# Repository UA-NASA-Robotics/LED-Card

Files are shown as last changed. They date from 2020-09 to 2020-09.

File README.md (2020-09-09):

# LED-Card
LED Card for the 2020-21 bot

## Design Specs

Interfaces with LED buffers for neopixels

Flash different statuses (listed below)

## CAN Bus information

### Status Lights
Red/Blue: Not connected

Green: Connected in Manual mode

Purple: Connected in Autonomous mode

### Planned features
Scrolling colors (flashy)

Digging mode colors

More Statuses

Overall more awesomeness

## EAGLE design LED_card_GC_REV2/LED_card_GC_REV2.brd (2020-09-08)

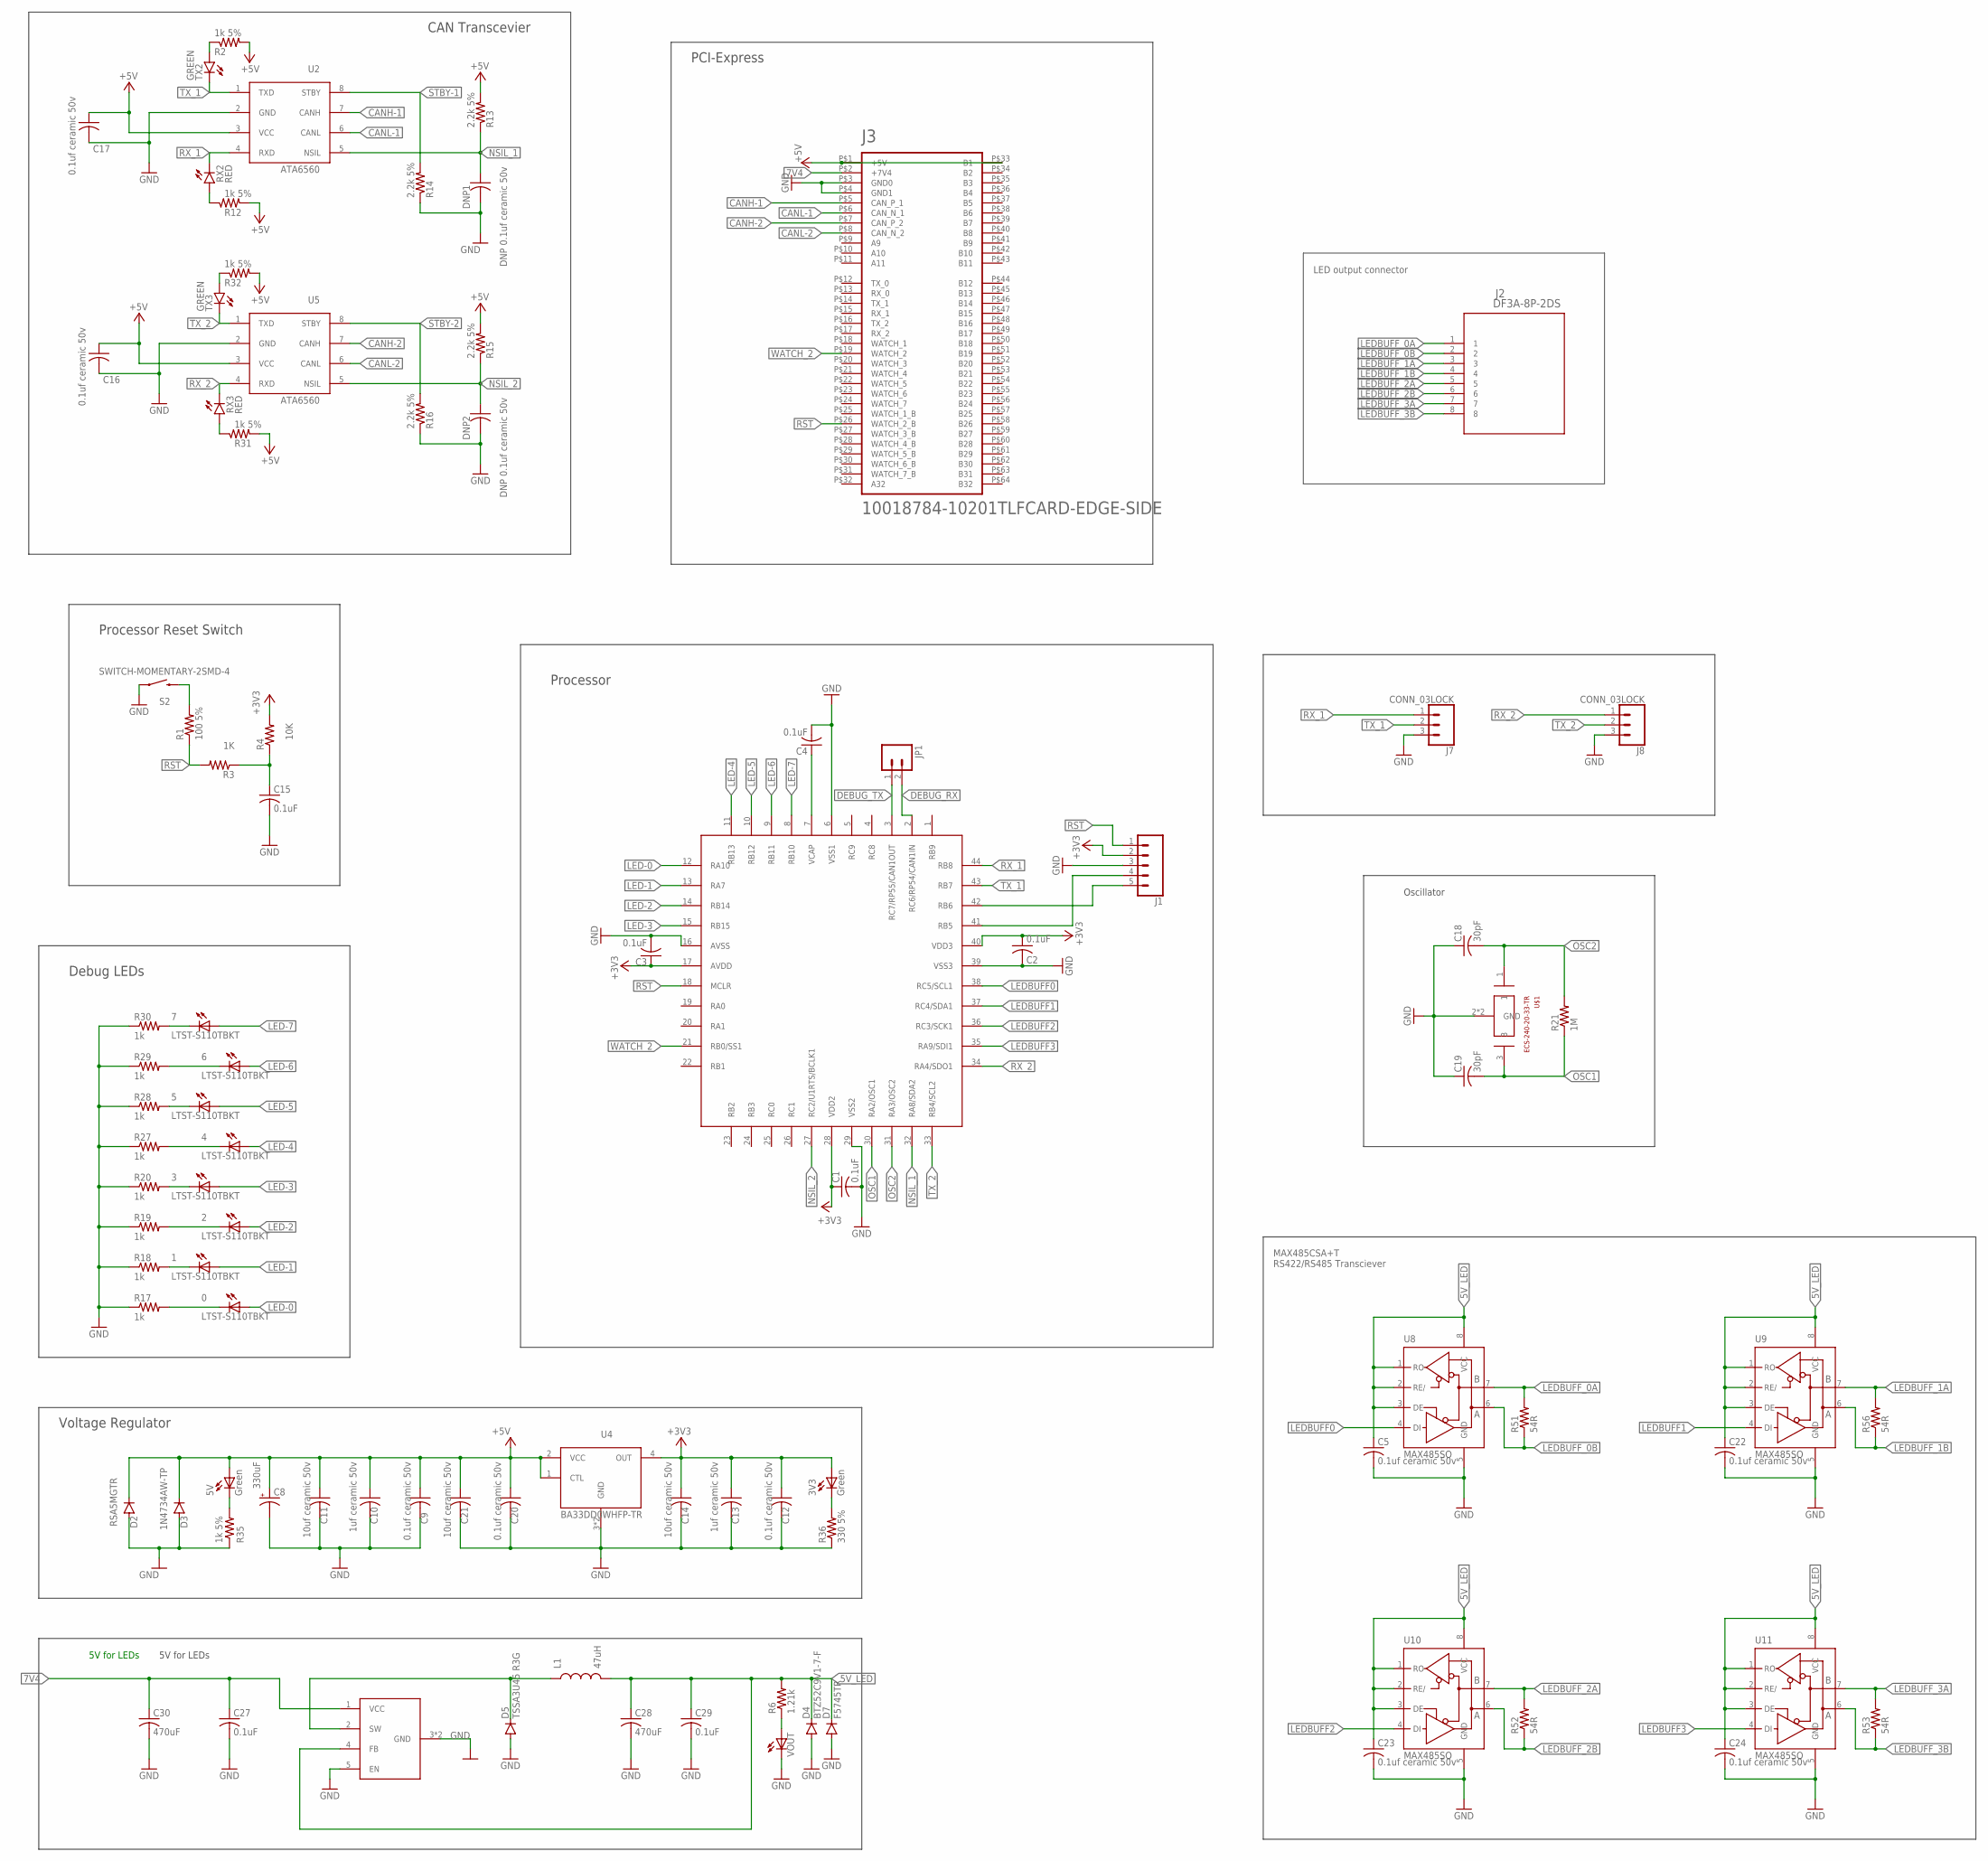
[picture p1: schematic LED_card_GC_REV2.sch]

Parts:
0, 1, 2, 3, 4, 5, 6, 7: LTST-S110TBKT; LED-90
3V3, 5V: Green; LED-90
C1, C2, C3, C4, C15: 0.1uF; C0805
C5, C9, C12, C16, C17, C20, C22, C23, C24: 0.1uf ceramic 50v; C0805
C8: 330uF; 140CLH-1014
C10, C13: 1uf ceramic 50v; C0805
C11, C14, C21: 10uf ceramic 50v; C0805
C18, C19: 30pF; C0805
C27, C29: 0.1uF; C1825
C28, C30: 470uF; C1825
D2: RSA5MGTR; SOD123
D3: 1N4734AW-TP; SOD123
D4: BTZ52C9V1-7-F; SOD123
D5: TSSA3U45 R3G; DO214AC
D7: F5745TR; SOD123
DNP1, DNP2: DNP 0.1uf ceramic 50v; C0805
J1: CONN_05LOCK; 1X05_LOCK
J2: DF3A-8P-2DS; CON8_1X8_R_DF3
J3: 10018784-10201TLFCARD-EDGE-SIDE; CARDEDGE_SIDE
J7, J8: CONN_03LOCK; 1X03_LOCK
JP1: CONN_02PTH; 1X02
L1: 47uH; 0805
R1: 100 5%; R0805
R2, R12, R31, R32, R35: 1k 5%; R0805
R3: 1K; R0805
R4: 10K; R0805
R6: 1.21k; R0805
R13, R14, R15, R16: 2.2k 5%; R0805
R17, R18, R19, R20, R27, R28, R29, R30: 1k; R0805
R21: 1M; R0805
R36: 330 5%; R0805
R51, R52, R53, R56: 54R; 0805
RX2, RX3: RED; CHIP-LED0805
S2: SWITCH-MOMENTARY-2SMD-4; TACTILE_SWITCH_TALL
TX2, TX3: GREEN; CHIP-LED0805
U2, U5: ATA6560; SO08
U3: DSPIC33EP512GM604; TQFP-44
U4: BA33DD0WHFP-TR; HRP5
U8, U9, U10, U11: MAX485SO; SO08
U$1: ECS-240-20-33-TR; ECX-32
U$3: TS2596CM550; HRP5
VOUT1: VOUT; CHIP-LED0805

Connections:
5V_LED: C5.1, C22.1, C23.1, C24.1, C28.1, C29.1, D4.C, D7.C, L1.2, R6.2, U8.1 (RO), U8.2 (RE/), U8.3 (DE), U8.8 (VCC), U9.1 (RO), U9.2 (RE/), U9.3 (DE), U9.8 (VCC), U10.1 (RO), U10.2 (RE/), U10.3 (DE), U10.8 (VCC), U11.1 (RO), U11.2 (RE/), U11.3 (DE), U11.8 (VCC), U$3.4 (FB)
7V4: C27.1, C30.1, J3.P$2 (+7V4), U$3.1 (VCC)
+3V3: 3V3.+ (A+), C1.1, C2.1, C3.1, C12.1, C13.1, C14.1, J1.2, R4.2, U3.17 (AVDD), U3.28 (VDD2), U3.40 (VDD3), U4.4 (OUT)
+5V: 5V.+ (A+), C8.+, C9.1, C10.1, C11.1, C16.1, C17.1, C20.1, C21.1, D2.C, D3.C, J3.P$1 (+5V), J3.P$33 (B1), R2.2, R12.2, R13.2, R15.2, R31.2, R32.2, U2.3 (VCC), U4.1 (CTL), U4.2 (VCC), U5.3 (VCC)
CANH-1: J3.P$5 (CAN_P_1), U2.7 (CANH)
CANH-2: J3.P$7 (CAN_P_2), U5.7 (CANH)
CANL-1: J3.P$6 (CAN_N_1), U2.6 (CANL)
CANL-2: J3.P$8 (CAN_N_2), U5.6 (CANL)
DEBUG_RX: JP1.2, U3.2 (RC6/RP54/CAN1IN)
DEBUG_TX: JP1.1, U3.3 (RC7/RP55/CAN1OUT)
GND: C1.2, C2.2, C3.2, C4.2, C5.2, C8.-, C9.2, C10.2, C11.2, C12.2, C13.2, C14.2, C15.2, C16.2, C17.2, C18.1, C19.1, C20.2, C21.2, C22.2, C23.2, C24.2, C27.2, C28.2, C29.2, C30.2, D2.A, D3.A, D4.A, D5.A, D7.A, DNP1.2, DNP2.2, J1.3, J3.P$3 (GND0), J3.P$4 (GND1), J7.3, J8.3, R14.1, R16.1, R17.1, R18.1, R19.1, R20.1, R27.1, R28.1, R29.1, R30.1, R35.1, R36.1, S2.A2 (1), U2.2 (GND), U3.6 (VSS1), U3.16 (AVSS), U3.29 (VSS2), U3.39 (VSS3), U4.3 (GND), U4.G (GND), U5.2 (GND), U8.5 (GND), U9.5 (GND), U10.5 (GND), U11.5 (GND), U$1.2 (GND), U$1.4 (GND), U$3.3 (GND), U$3.5 (EN), U$3.G (GND), VOUT1.C
LED-0: 0.+ (A+), U3.12 (RA10)
LED-1: 1.+ (A+), U3.13 (RA7)
LED-2: 2.+ (A+), U3.14 (RB14)
LED-3: 3.+ (A+), U3.15 (RB15)
LED-4: 4.+ (A+), U3.11 (RB13)
LED-5: 5.+ (A+), U3.10 (RB12)
LED-6: 6.+ (A+), U3.9 (RB11)
LED-7: 7.+ (A+), U3.8 (RB10)
LEDBUFF0: U3.38 (RC5/SCL1), U8.4 (DI)
LEDBUFF1: U3.37 (RC4/SDA1), U9.4 (DI)
LEDBUFF2: U3.36 (RC3/SCK1), U10.4 (DI)
LEDBUFF3: U3.35 (RA9/SDI1), U11.4 (DI)
LEDBUFF_0A: J2.1, R51.2, U8.7 (B)
LEDBUFF_0B: J2.2, R51.1, U8.6 (A)
LEDBUFF_1A: J2.3, R56.2, U9.7 (B)
LEDBUFF_1B: J2.4, R56.1, U9.6 (A)
LEDBUFF_2A: J2.5, R52.2, U10.7 (B)
LEDBUFF_2B: J2.6, R52.1, U10.6 (A)
LEDBUFF_3A: J2.7, R53.2, U11.7 (B)
LEDBUFF_3B: J2.8, R53.1, U11.6 (A)
unnamed: C15.1, R3.1, R4.1
unnamed: R1.2, S2.B2 (2)
unnamed: 5V.- (C-), R35.2
unnamed: 3V3.- (C-), R36.2
unnamed: J1.5, U3.42 (RB6)
unnamed: 6.- (C-), R29.2
unnamed: D5.C, L1.1, U$3.2 (SW)
unnamed: R6.1, VOUT1.A
unnamed: 7.- (C-), R30.2
unnamed: J1.4, U3.41 (RB5)
unnamed: C4.1, U3.7 (VCAP)
unnamed: 5.- (C-), R28.2
unnamed: 4.- (C-), R27.2
unnamed: 3.- (C-), R20.2
unnamed: 2.- (C-), R19.2
unnamed: 1.- (C-), R18.2
unnamed: 0.- (C-), R17.2
unnamed: R12.1, RX2.A
unnamed: R2.1, TX2.A
unnamed: R31.1, RX3.A
unnamed: R32.1, TX3.A
NSIL_1: DNP1.1, R13.1, U2.5 (NSIL), U3.32 (RA8/SDA2)
NSIL_2: DNP2.1, R15.1, U3.27 (RC2/U1RTS/BCLK1), U5.5 (NSIL)
OSC1: C19.2, R21.1, U3.30 (RA2/OSC1), U$1.3
OSC2: C18.2, R21.2, U3.31 (RA3/OSC2), U$1.1
RST: J1.1, J3.P$26 (WATCH_2_B), R1.1, R3.2, U3.18 (MCLR)
RX_1: J7.1, RX2.C, U2.4 (RXD), U3.44 (RB8)
RX_2: J8.1, RX3.C, U3.34 (RA4/SDO1), U5.4 (RXD)
STBY-1: R14.2, U2.8 (STBY)
STBY-2: R16.2, U5.8 (STBY)
TX_1: J7.2, TX2.C, U2.1 (TXD), U3.43 (RB7)
TX_2: J8.2, TX3.C, U3.33 (RB4/SCL2), U5.1 (TXD)
WATCH_2: J3.P$19 (WATCH_2), U3.21 (RB0/SS1)

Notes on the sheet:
Debug LEDs
Processor Reset Switch
Processor
Oscillator
Voltage Regulator
CAN Transcevier
PCI-Express
5V for LEDs
MAX485CSA+T RS422/RS485 Transciever
LED output connector

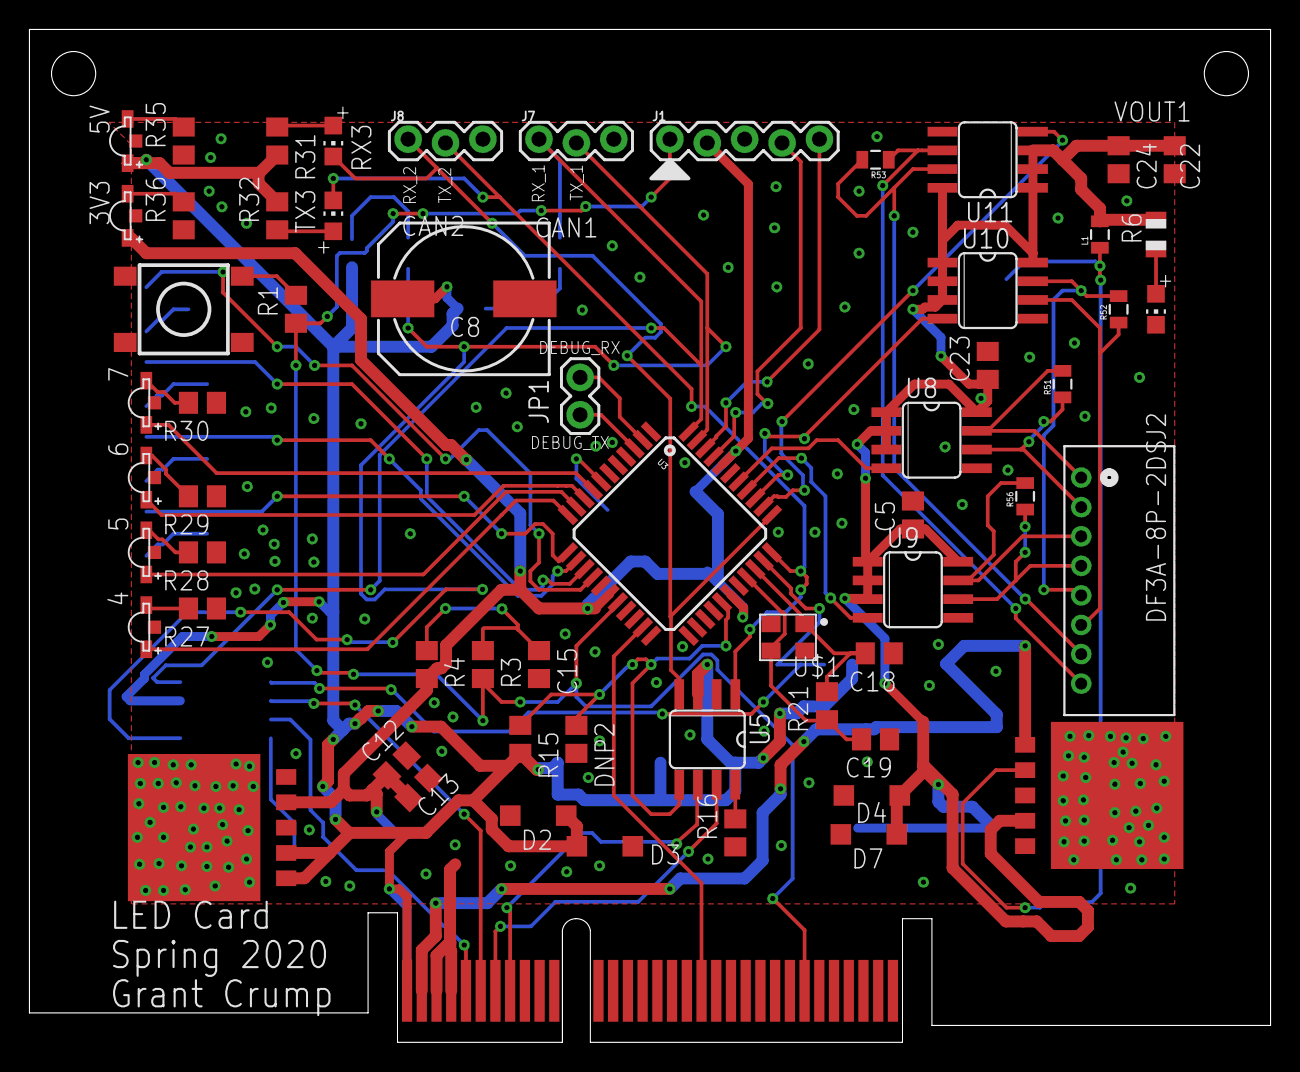
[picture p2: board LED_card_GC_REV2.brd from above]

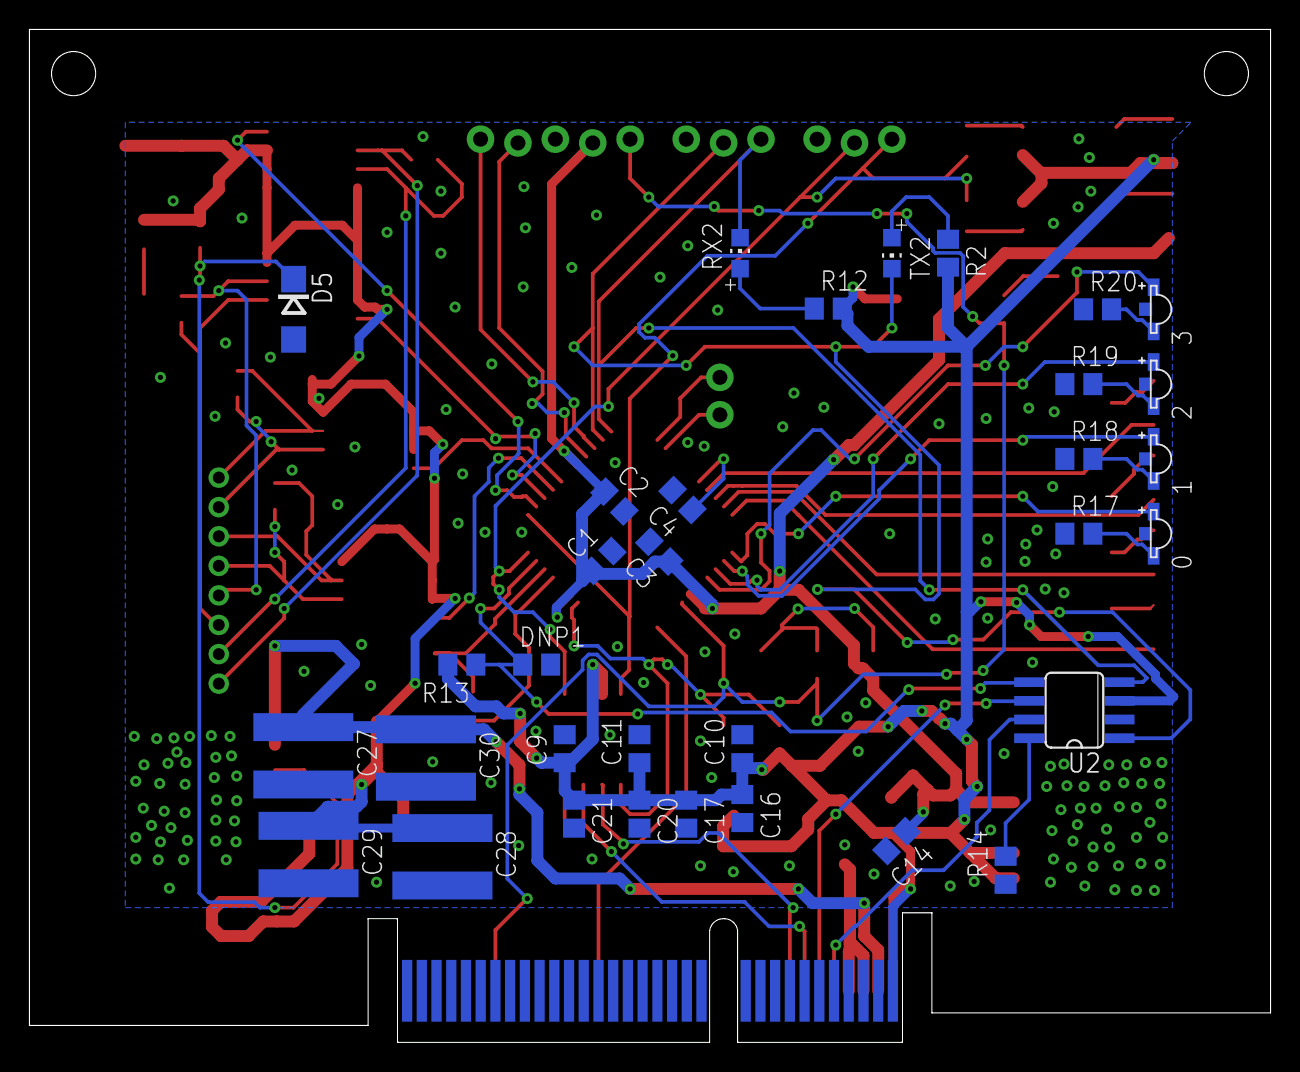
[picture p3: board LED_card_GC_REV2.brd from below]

Board: 2 copper layers, 84.3 x 68.8 mm, 93 parts (33 on the bottom side), 64 nets.

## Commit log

2020-09-08 Added EAGLE files
    [LED_card_GC_REV2.brd, LED_card_GC_REV2.sch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]
2020-09-09 Added .gitignore
    ignore CAMoutputs and old router/LED files

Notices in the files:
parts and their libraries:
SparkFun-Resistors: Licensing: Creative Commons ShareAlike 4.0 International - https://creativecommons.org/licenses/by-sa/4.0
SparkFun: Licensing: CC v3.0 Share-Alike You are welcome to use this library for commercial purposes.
